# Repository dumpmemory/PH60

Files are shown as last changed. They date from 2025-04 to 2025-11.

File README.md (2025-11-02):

English Version | [中文版](https://github.com/ph-design/PH60/blob/Rev.2/README-zh_CN.md)

---

# PH60 Rev.2
This is a mechanical keyboard with an ISO 60% layout, based on the ISO/IEC 9995 standard.

Watch the detailed introduction on Bilibili!

Bilibili: https://www.bilibili.com/video/BV19Txce7E6C/

We've made a brand new upgrade! Now we've iterated to Rev.2

PH60 Rev.1 Preview all color

## What's new compared to Rev.1
### PCB
We customized this keyboard according to our own ideas while also considering other users' opinions.
- Added the more mainstream ANSI layout, which most people should now feel familiar.

- The PCB has been reduced from 4 layers to 2 layers. Theoretically, the electrical performance has decreased, but it's sufficient for a keyboard, and the cost has been greatly reduced.

- Added support for RGB matrix lighting for both ANSI and ISO layouts.

- Temporarily removed the MOLEX connector and daughter board design as they were not stable enough.
PH60 RGB

- <b>Brand new multi-layout compatible PCB</b>. Compatible with ANSI/ISO/WK/WKL/HHKB, with meticulous routing. This PCB was carefully crafted by our team member [nonameC_](http://www.github.com/nonameCCC).

### Case
PH60 case
PH60 case

Rev2 version introduces innovative designs while maintaining printability, enhancing user experience.

- Magnetic top cover fixation, retaining the snap-fit design

- Innovative "pillow" foot support design, adjustable 7-degree and 0-degree input angles

- Gasket structure design, with specially made thickened positioning plate

- Fully compatible with GH60 standard PCB

- Optimized printing parameters for different printers and materials
  
New version introduction: https://www.bilibili.com/video/BV1fsB8YQELg/

## Design Philosophy

PH60 Rev2 aims to solve the problem of consumer-grade 3D printers being unable to print complete keyboard cases. Through modular design and innovative connection methods, we've achieved high-quality, customizable keyboard cases.

## Usage Guide

1. Download model files from the GitHub repository
2. Choose appropriate slicing parameters based on your printer (Bambu Lab users can get optimized configurations on MakerWorld)
3. Print each component
4. Complete keyboard assembly following the [Assembly Steps](#Assembly-Steps)

---
## Project Structure
```
PH60 Rev.2
├── Case_Model_Rev2                 # Keyboard case 3D model files
├── LICENSE                         # Project license file
├── PCB_Model_Rev2                  # Motherboard 3D model files
├── PCB_Rev2                        # Motherboard PCB design files
├── Plate                           # Positioning plate files
├── Preview                         # Keyboard preview images
├── Production                      # Production files
├── README-zh_CN.md                 # Chinese README
└── README.md                       # English README
```

## Specifications

1. 3D printed case, suitable for any 3D printer with a print size over 250mm x 250mm.
2. Gasket structure for a softer and more flexible typing experience.
3. Designed for plate-mount stabilizers for better typing experience.
4. Equipped with [Raspberry Pi RP2040](https://www.raspberrypi.com/products/rp2040/) microcontroller.
5. Supports open-source [QMK firmware](https://qmk.fm/) and [VIA configuration](https://www.caniusevia.com/) (configured via JSON file).

## Assembly Steps

1. Align the internal markers of the central bottom case and two side cases, ensuring the text direction is consistent. Press the side cases into the central bottom case.

2. Similarly, assemble the two top cover components. After assembly, the top cover should align perfectly. Use a rubber mallet if necessary.

3. Ensure consistent magnet polarity, then press magnets into all designated holes in the bottom case, top cover, and pillow. Use glue if needed.

4. First secure the left snap-fit, then release the cover, allowing the right side to be secured by magnets.

5. Flip the case and secure silicone anti-slip pads to the case and pillow.
   
6. Install the PCB

For more detailed printing and installation steps, please refer to [MakerWorld](https://makerworld.com/zh/models/808113).

## Precautions

If you're hand-soldering the PCB, avoid using Sn42Bi58 low-temperature solder paste. Otherwise, under high-intensity use, it may lead to false soldering between the PCB and hot-swap sockets.

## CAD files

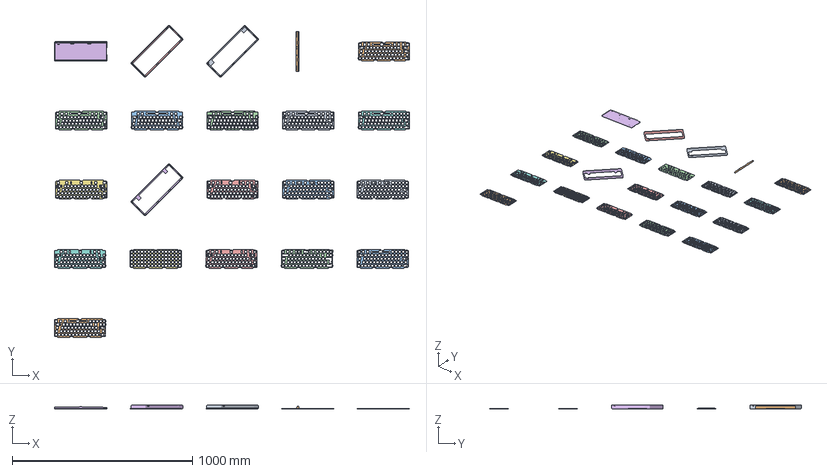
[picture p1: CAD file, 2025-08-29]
Case/PH60i/For Bambu Studio.3mf
1971.1 x 1732.9 x 19.7 mm
outer_case_HHKB
PLANK_(1)
63_Universal_PCBS
WK_PCBS
inner_case
PLANK
HHKB_PCBS
LS64_SSPACE_SB
pillow
LS64_SSPACE
ISO
ANSI_PCBS
outer_case_WKL
WKL_PCBS
LS64
ANSI_SS_SB
ANSI
HHKB
HHKB_Thick
outer_case

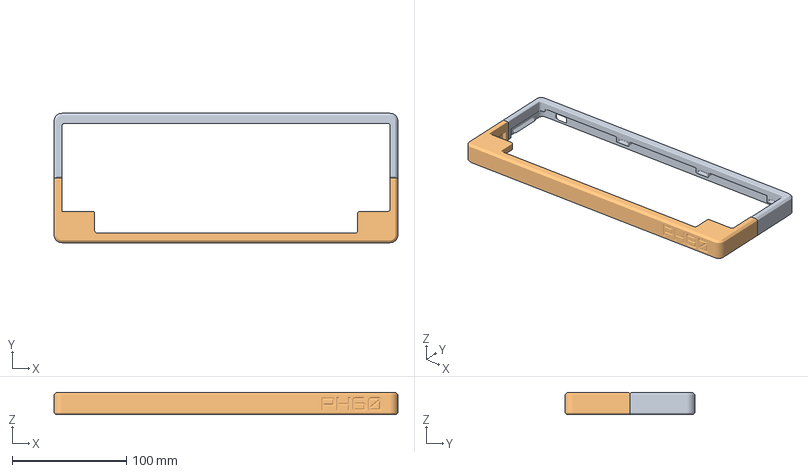
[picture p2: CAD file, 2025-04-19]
Case/PH60Rev2/upper_hhkb.3mf
301.4 x 113.5 x 19.7 mm
outer_case_2
hhkb_outer_case_b

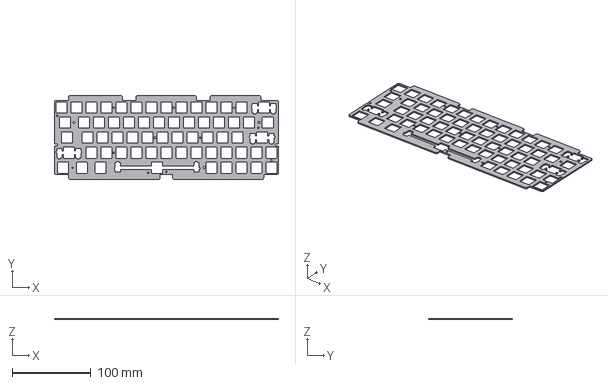
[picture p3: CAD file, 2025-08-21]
Plates_Rev2/3D Model/CAD/K64H3.step
284.2 x 106.2 x 1.50 mm

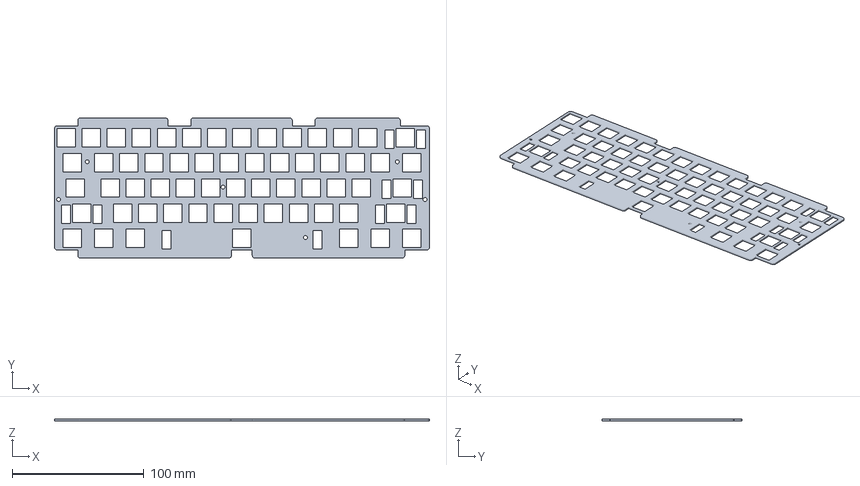
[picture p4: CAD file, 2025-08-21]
Plates_Rev2/3D Model/plate_wk.3mf
284.2 x 106.2 x 1.50 mm

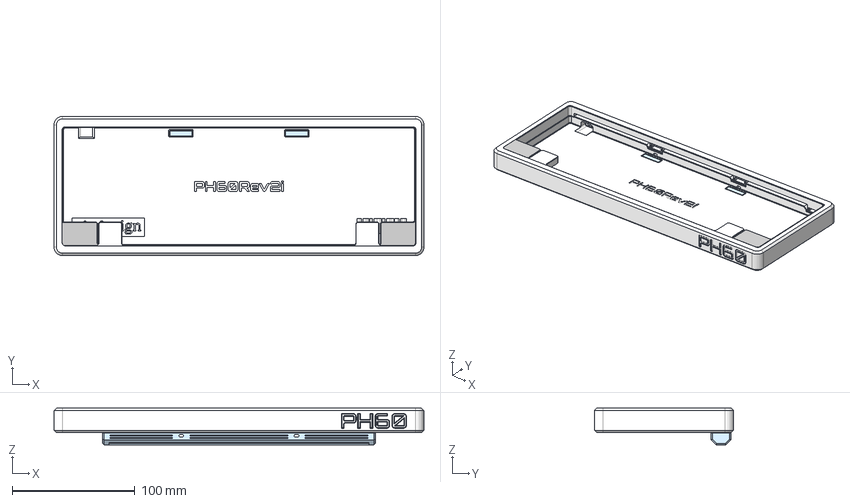
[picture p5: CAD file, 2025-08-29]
Case/PH60i/PH60_Kit_Rev2.2 H2D.step
301.4 x 113.5 x 29.8 mm

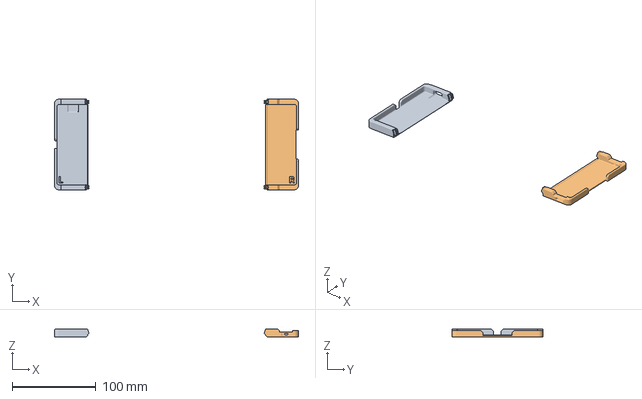
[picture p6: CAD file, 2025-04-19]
Case/PH60Rev2/inner_side.3mf
292.1 x 108.5 x 9.90 mm
inner_case_left
inner_case_right

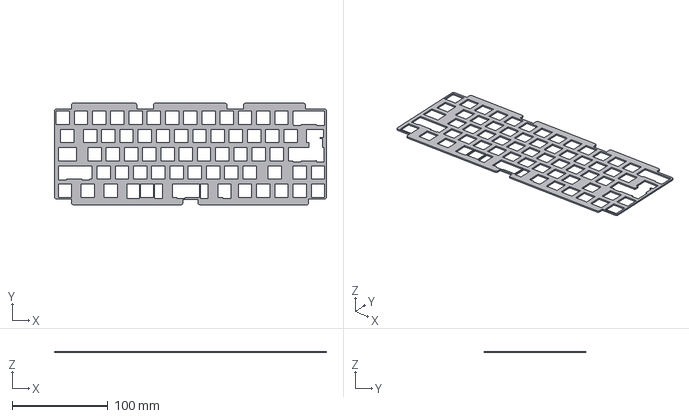
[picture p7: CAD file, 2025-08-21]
Plates_Rev2/3D Model/CAD/63_Universal.step
284.2 x 106.2 x 1.50 mm

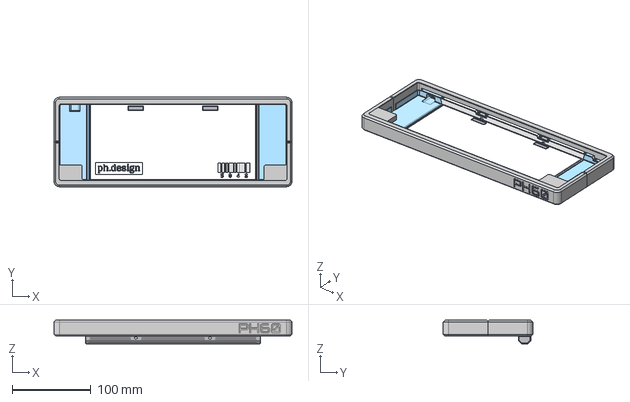
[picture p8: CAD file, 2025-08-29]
Case/PH60i/PH60_Kit_Rev2.2.step
301.4 x 113.5 x 29.8 mm

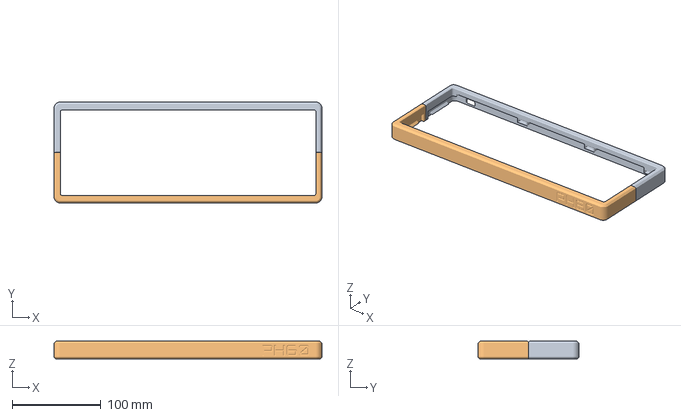
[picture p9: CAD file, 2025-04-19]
Case/PH60Rev2/upper.3mf
301.4 x 113.5 x 19.7 mm
outer_case_2
outer_case_1

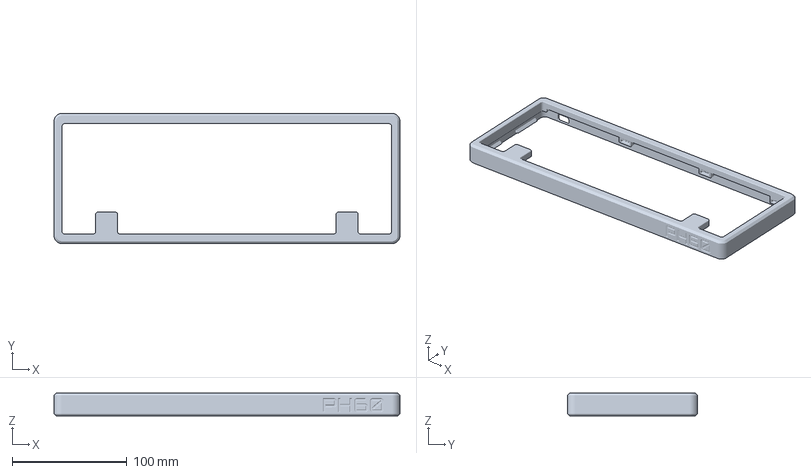
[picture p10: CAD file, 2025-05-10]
Case/PH60i/upper_wkl.3mf
301.4 x 113.5 x 19.7 mm

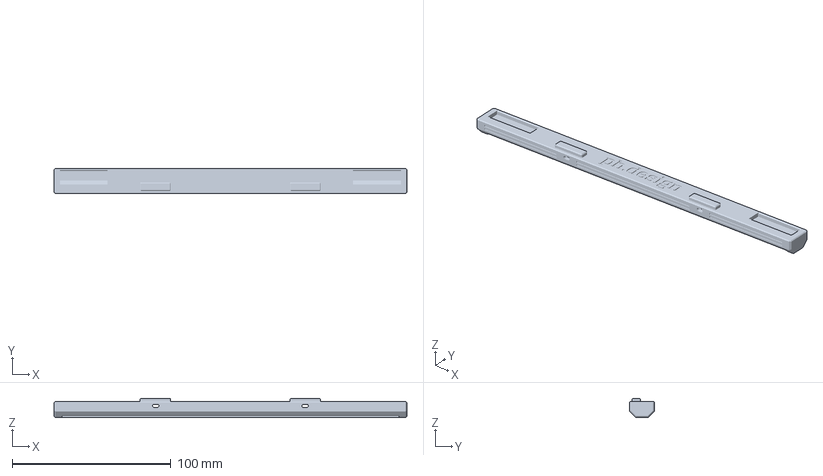
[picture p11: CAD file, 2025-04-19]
Case/PH60Rev2/pillow.3mf
222.1 x 16.0 x 12.1 mm

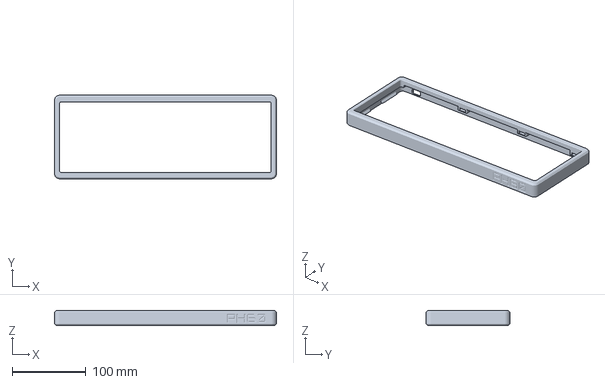
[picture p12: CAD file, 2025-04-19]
Case/PH60i/upper.3mf
301.4 x 113.5 x 19.7 mm

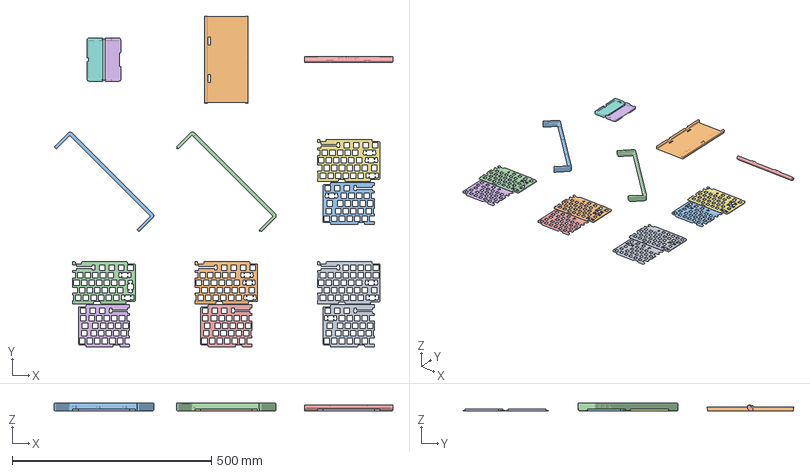
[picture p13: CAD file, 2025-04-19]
Case/PH60Rev2/PH60_suite.3mf
850.6 x 831.3 x 19.7 mm
thick_plate_r_(1) x 3
inner_case_mid
outer_case_2
outer_case_1
pillow
inner_case_right
inner_case_left
thick_plate_l_(1) x 3
thick_plate_r_(2)
thick_plate_l_(2)

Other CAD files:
Plates_Rev2/3D Model/plate_63.3mf
Plates_Rev2/3D Model/CAD/63.step
Plates_Rev2/3D Model/plate_plank.3mf
Plates_Rev2/3D Model/CAD/WK_PCBS.step
Plates_Rev2/3D Model/plate_63_universal_pcbs.3mf
Case/PH60Rev2/For Bambu Studio.3mf
Case/PH60Rev2/inner_mid.3mf
Case/PH60i/inner.3mf
Case/PH60i/pillow.3mf
Case/PH60i/upper_hhkb.3mf
Plates_Rev2/3D Model/CAD/ANSI.step
Plates_Rev2/3D Model/CAD/ANSI_PCBS.step
Plates_Rev2/3D Model/CAD/ANSI_SS_SB.step
Plates_Rev2/3D Model/CAD/HHKB.step
Plates_Rev2/3D Model/CAD/HHKB_PCBS.step
Plates_Rev2/3D Model/CAD/HHKB_thick.step
Plates_Rev2/3D Model/CAD/ISO.step
Plates_Rev2/3D Model/CAD/LS64.step
Plates_Rev2/3D Model/CAD/LS64_SSPACE.step
Plates_Rev2/3D Model/CAD/LS64_SSPACE_SB.step
Plates_Rev2/3D Model/CAD/PLANK.step
Plates_Rev2/3D Model/CAD/WKL_PCBS.step
Plates_Rev2/3D Model/k64h3.3mf
Plates_Rev2/3D Model/plate_K64H3MZ.3mf
Plates_Rev2/3D Model/plate_ansi.3mf
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

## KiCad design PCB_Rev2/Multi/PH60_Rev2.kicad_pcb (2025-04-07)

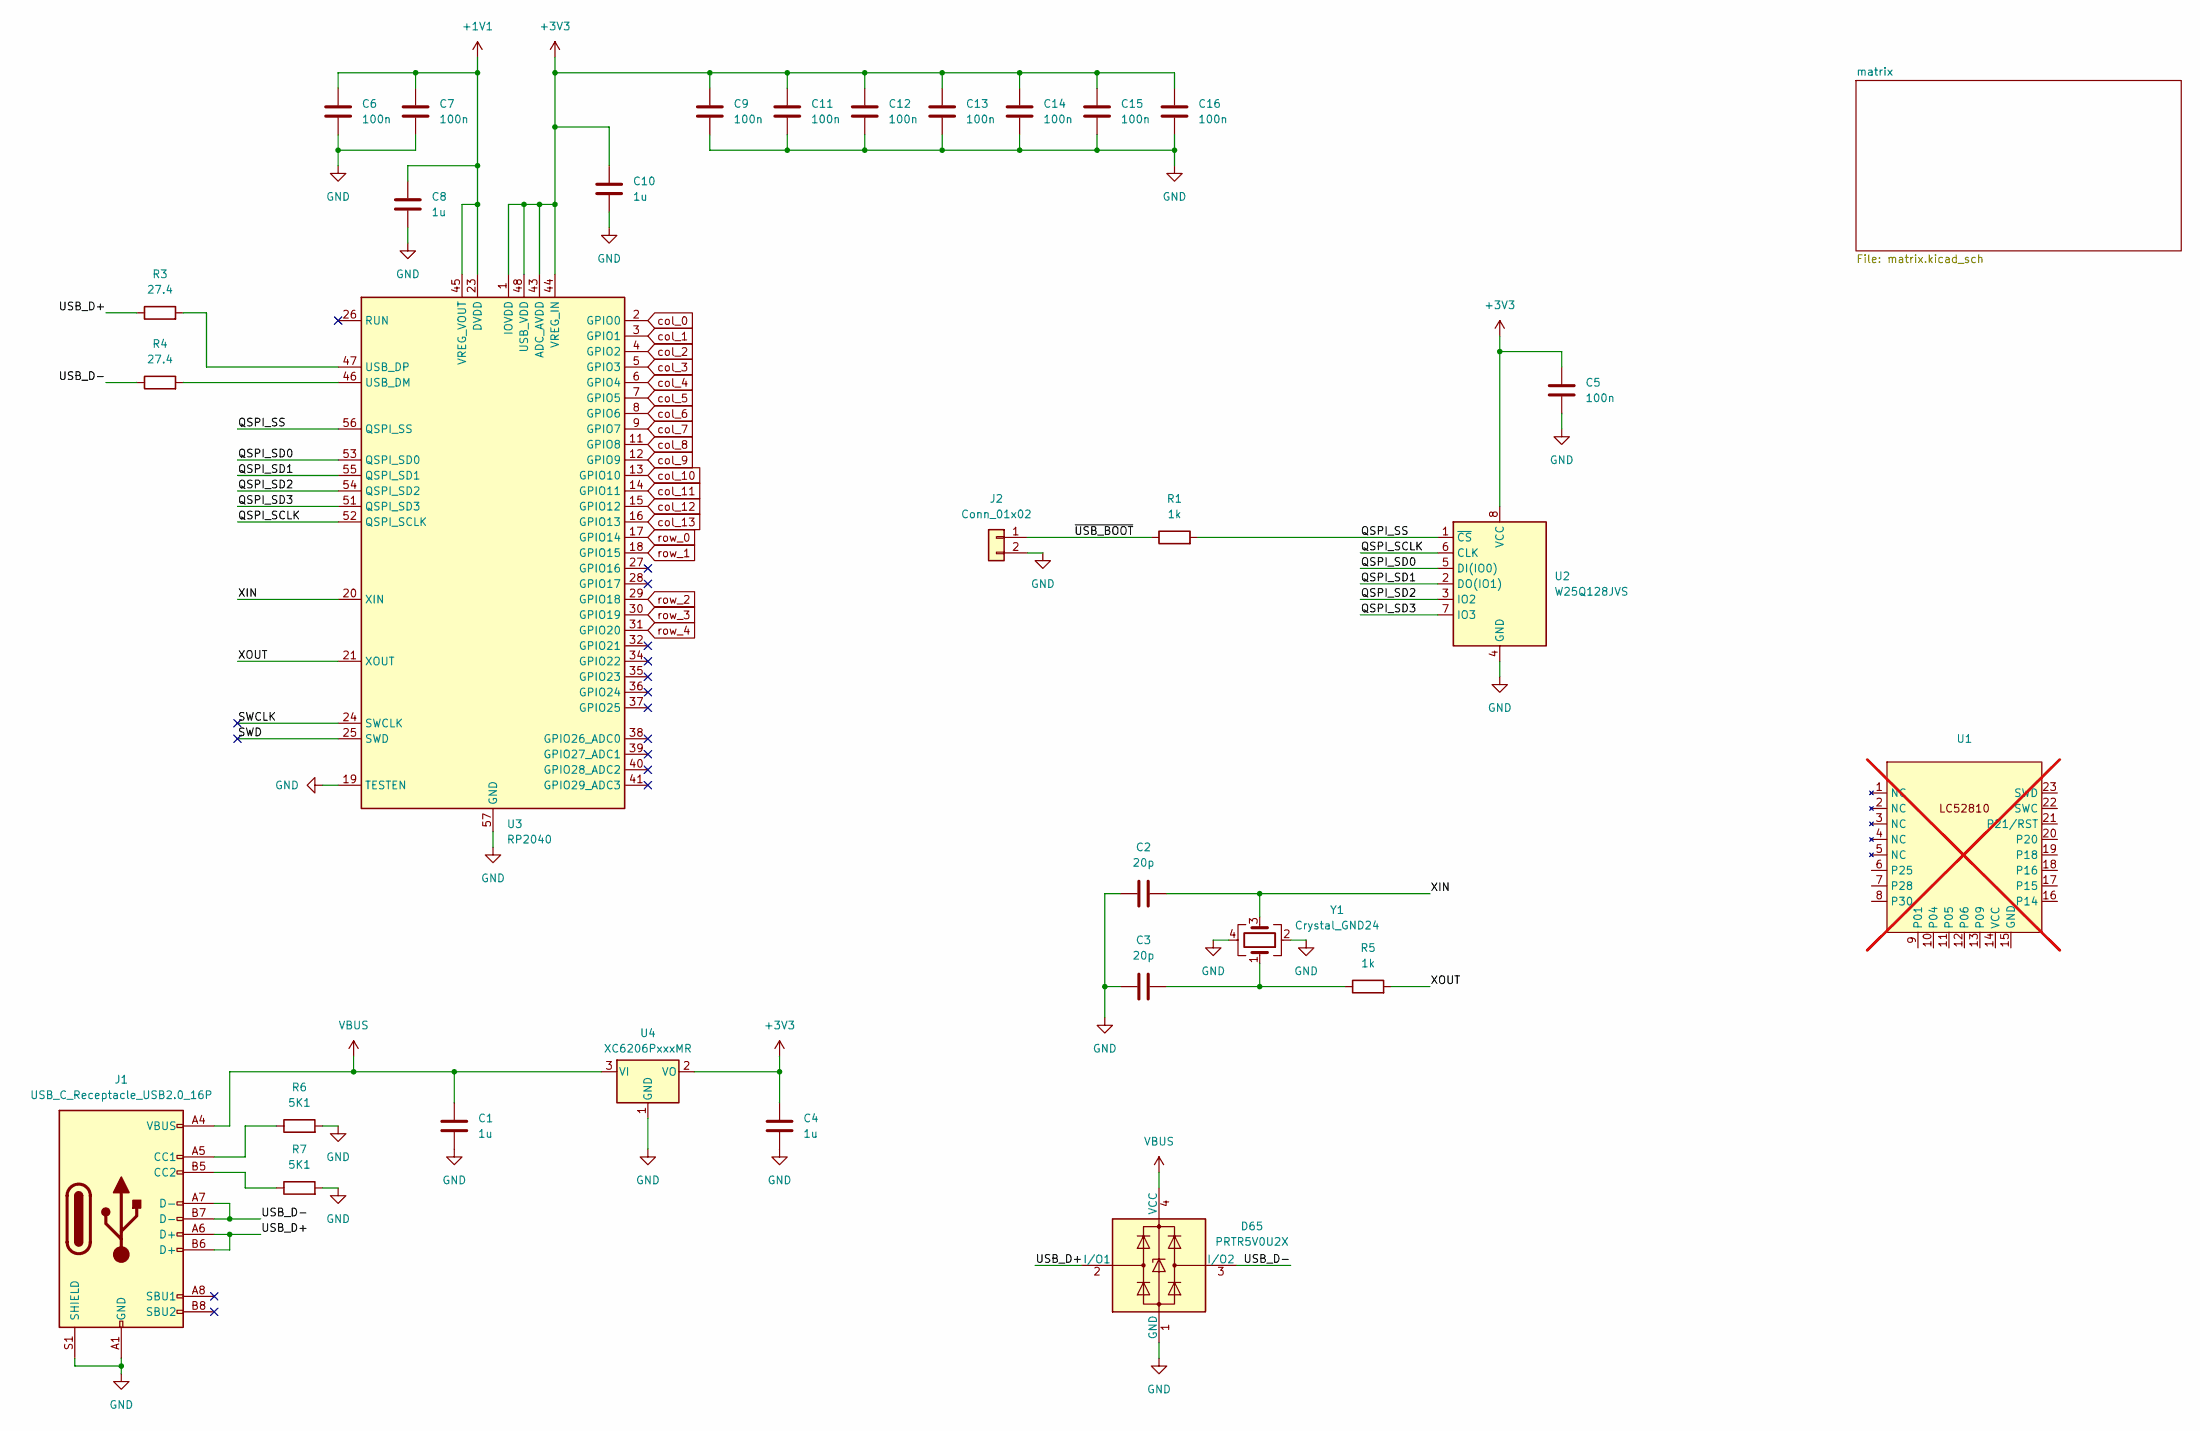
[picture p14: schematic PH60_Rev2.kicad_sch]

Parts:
C1, C4, C8, C10: 1u; C_0402_1005Metric
C2, C3: 20p; C_0402_1005Metric
C5, C6, C7, C9, C11, C12, C13, C14, C15, C16: 100n; C_0402_1005Metric
D65: PRTR5V0U2X; SOT-143
J1: USB_C_Receptacle_USB2.0_16P; USB_C_Receptacle_GCT_USB4105-xx-A_16P_TopMnt_Horizontal
J2: Conn_01x02; PinHeader_1x02_P1.27mm_Vertical
R1, R5: 1k; R_0402_1005Metric
R3, R4: 27.4; R_0402_1005Metric
R6, R7: 5K1; R_0402_1005Metric
U1: nRF52810_Module; not fitted
U2: W25Q128JVS; Winbond_USON-8-1EP_3x2mm_P0.5mm_EP0.2x1.6mm
U3: RP2040; QFN-56-1EP_7x7mm_P0.4mm_EP3.2x3.2mm
U4: XC6206PxxxMR; SOT-23-3
Y1: Crystal_GND24; Crystal_SMD_3225-4Pin_3.2x2.5mm

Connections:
+1V1: C6.1, C7.1, C8.1, U3.23 (DVDD), U3.45 (VREG_VOUT), U3.50 (DVDD)
+3V3: C4.1, C5.1, C9.1, C10.1, C11.1, C12.1, C13.1, C14.1, C15.1, C16.1, U2.8 (VCC), U3.1 (IOVDD), U3.10 (IOVDD), U3.22 (IOVDD), U3.33 (IOVDD), U3.42 (IOVDD), U3.43 (ADC_AVDD), U3.44 (VREG_IN), U3.48 (USB_VDD), U3.49 (IOVDD), U4.2 (VO)
/QSPI_SCLK: U2.6 (CLK), U3.52 (QSPI_SCLK)
/QSPI_SD0: U2.5 (DI(IO0)), U3.53 (QSPI_SD0)
/QSPI_SD1: U2.2 (DO(IO1)), U3.55 (QSPI_SD1)
/QSPI_SD2: U2.3 (IO2), U3.54 (QSPI_SD2)
/QSPI_SD3: U2.7 (IO3), U3.51 (QSPI_SD3)
/QSPI_SS: R1.2, U2.1 (~CS), U3.56 (QSPI_SS)
/SWCLK: U3.24 (SWCLK)
/SWD: U3.25 (SWD)
/USB_D+: D65.2 (I/O1), J1.A6 (D+), J1.B6 (D+), R3.1
/USB_D-: D65.3 (I/O2), J1.A7 (D-), J1.B7 (D-), R4.1
/XIN: C2.1, U3.20 (XIN), Y1.3
/XOUT: R5.2, U3.21 (XOUT)
/~USB_BOOT: J2.1, R1.1
GND: C1.2, C2.2, C3.2, C4.2, C5.2, C6.2, C7.2, C8.2, C9.2, C10.2, C11.2, C12.2, C13.2, C14.2, C15.2, C16.2, D65.1 (GND), J1.A1 (GND), J1.A12 (GND), J1.B1 (GND), J1.B12 (GND), J1.S1 (SHIELD), J2.2, R6.2, R7.2, U2.4 (GND), U3.19 (TESTEN), U3.57 (GND), U4.1 (GND), Y1.2, Y1.4
unnamed: C3.1, R5.1, Y1.1
unnamed: J1.A5 (CC1), R6.1
unnamed: J1.B5 (CC2), R7.1
unnamed: R4.2, U3.46 (USB_DM)
unnamed: R3.2, U3.47 (USB_DP)
VBUS: C1.1, D65.4 (VCC), J1.A4 (VBUS), J1.A9 (VBUS), J1.B4 (VBUS), J1.B9 (VBUS), U4.3 (VI)
col_0: U3.2 (GPIO0); also elsewhere on the board
col_1: U3.3 (GPIO1); also elsewhere on the board
col_2: U3.4 (GPIO2); also elsewhere on the board
col_3: U3.5 (GPIO3); also elsewhere on the board
col_4: U3.6 (GPIO4); also elsewhere on the board
col_5: U3.7 (GPIO5); also elsewhere on the board
col_6: U3.8 (GPIO6); also elsewhere on the board
col_7: U3.9 (GPIO7); also elsewhere on the board
col_8: U3.11 (GPIO8); also elsewhere on the board
col_9: U3.12 (GPIO9); also elsewhere on the board
col_10: U3.13 (GPIO10); also elsewhere on the board
col_11: U3.14 (GPIO11); also elsewhere on the board
col_12: U3.15 (GPIO12); also elsewhere on the board
col_13: U3.16 (GPIO13); also elsewhere on the board
row_0: U3.17 (GPIO14); also elsewhere on the board
row_1: U3.18 (GPIO15); also elsewhere on the board
row_2: U3.29 (GPIO18); also elsewhere on the board
row_3: U3.30 (GPIO19); also elsewhere on the board
row_4: U3.31 (GPIO20); also elsewhere on the board

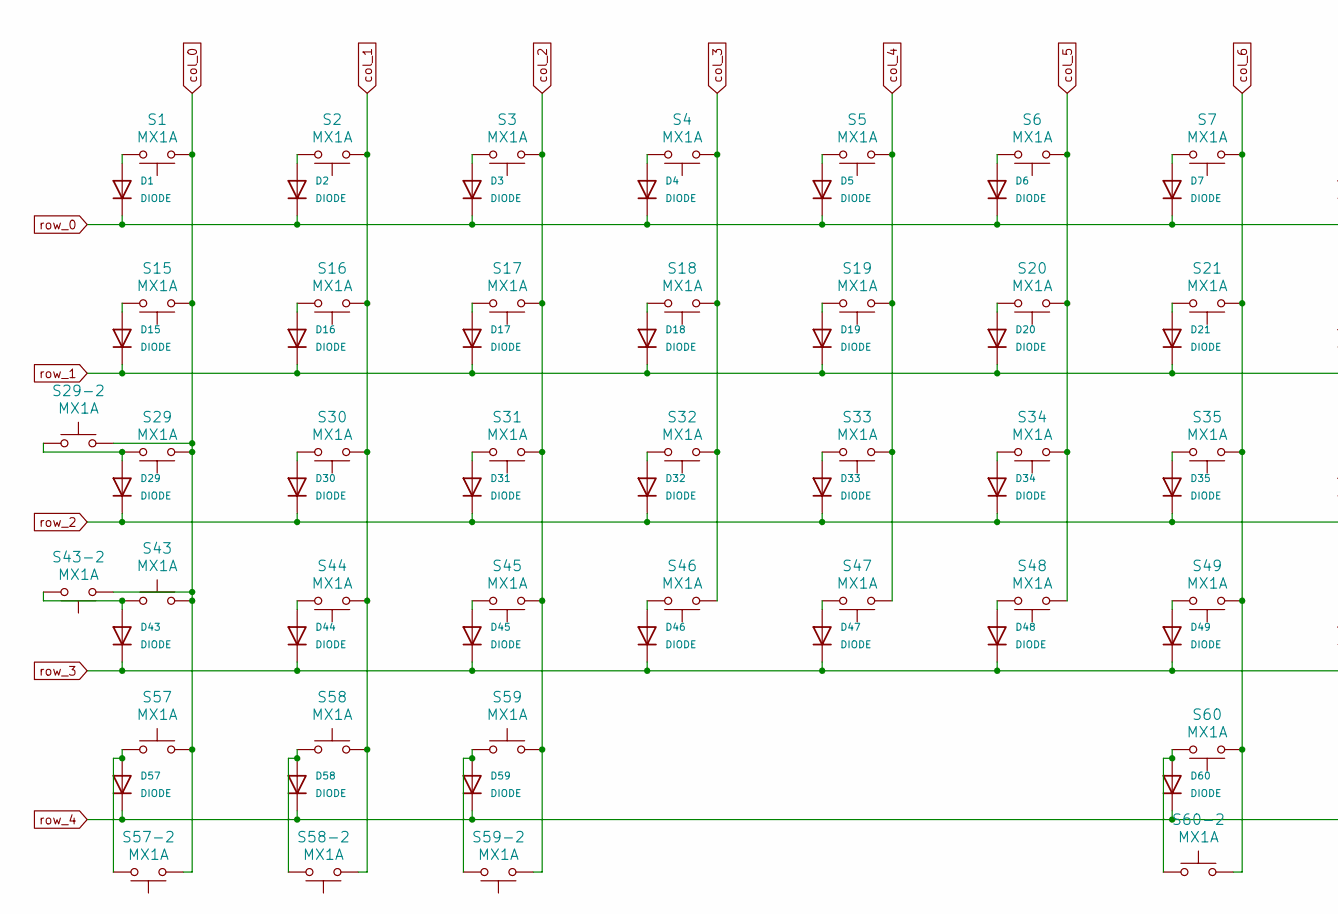
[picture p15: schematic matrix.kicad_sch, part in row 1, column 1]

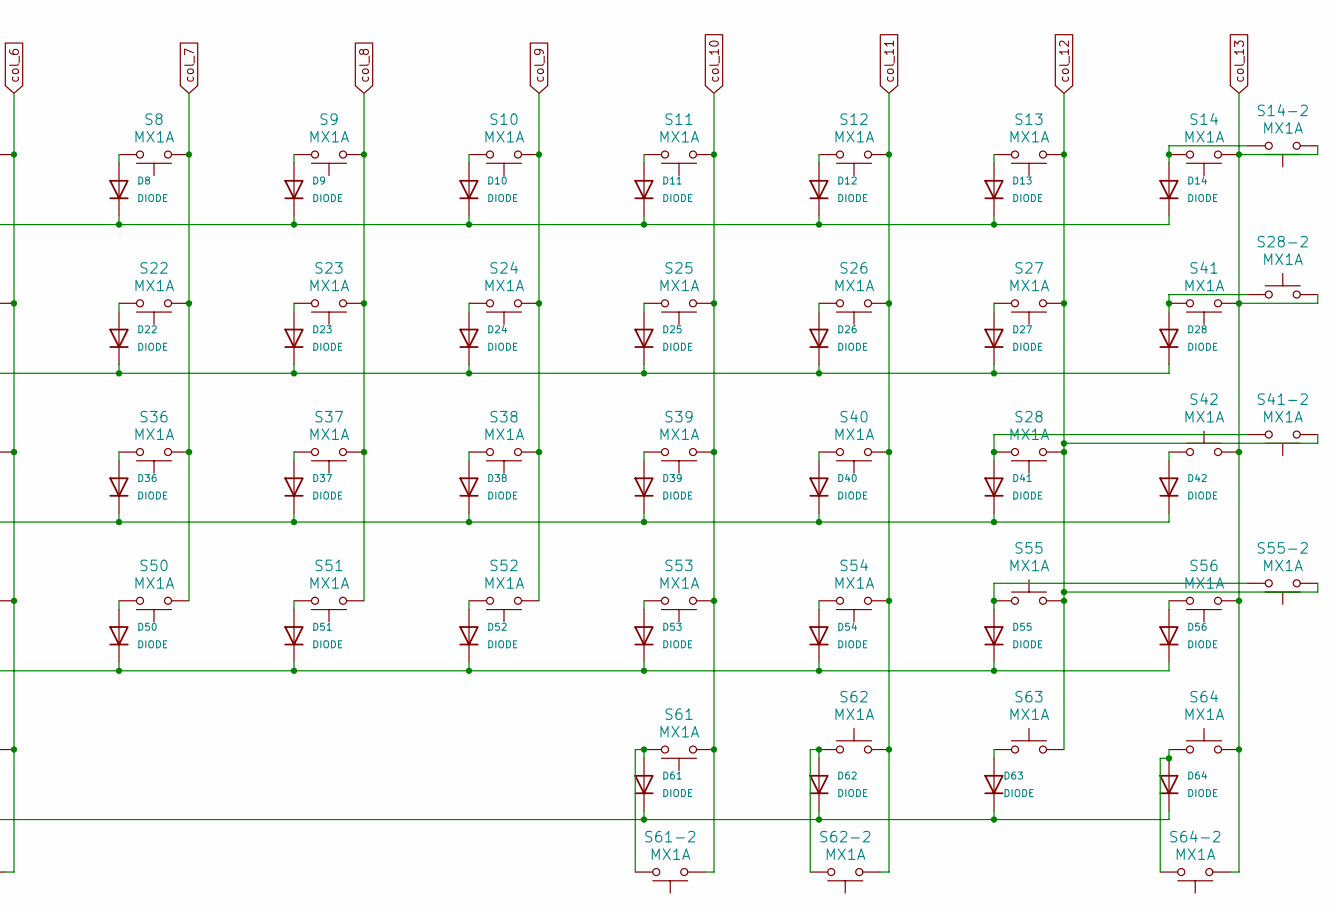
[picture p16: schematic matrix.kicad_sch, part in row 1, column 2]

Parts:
D1, D2, D3, D4, D5, D6, D7, D8, D9, D10, D11, D12, D13, D14, D15, D16, D17, D18, D19, D20, D21, D22, D23, D24, D25, D26, D27, D28, D29, D30, D31, D32, D33, D34, D35, D36, D37, D38, D39, D40, D41, D42, D43, D44, D45, D46, D47, D48, D49, D50, D51, D52, D53, D54, D55, D56, D57, D58, D59, D60, D61, D62, D63, D64: DIODE; D_SOD-123
S1, S2, S3, S4, S5, S6, S7, S8, S9, S10, S11, S12, S13, S14-2, S16, S17, S18, S19, S20, S21, S22, S23, S24, S25, S26, S27, S30, S31, S32, S33, S34, S35, S36, S37, S38, S39, S40, S41, S42, S44, S45, S46, S47, S48, S49, S50, S51, S52, S53, S54, S56, S58-2, S62-2: MX1A; SW_Hotswap_Kailh_MX_Plated_1.00u
S14: MX1A; SW_Hotswap_Kailh_MX_Plated_2.00u
S15, S57-2, S59-2, S61-2, S64-2: MX1A; SW_Hotswap_Kailh_MX_Plated_1.50u
S28: MX1A; SW_Hotswap_Kailh_MX_Plated_ISOEnter_90deg
S28-2: MX1A; SW_Hotswap_Kailh_MX_Plated_1.50u_90deg
S29, S55: MX1A; SW_Hotswap_Kailh_MX_Plated_1.75u
S29-2, S43, S57, S58, S59, S61, S62, S63, S64: MX1A; SW_Hotswap_Kailh_MX_Plated_1.25u
S41-2: MX1A; SW_Hotswap_Kailh_MX_Plated_2.25u_90deg
S43-2: MX1A; SW_Hotswap_Kailh_MX_Plated_2.25u
S55-2: MX1A; SW_Hotswap_Kailh_MX_Plated_2.75u
S60: MX1A; SW_Hotswap_Kailh_MX_Plated_6.25u
S60-2: MX1A; SW_Hotswap_Kailh_MX_Plated_7.00u

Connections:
unnamed: D1.2 (A), S1.1
unnamed: D2.2 (A), S2.1
unnamed: D3.2 (A), S3.1
unnamed: D4.2 (A), S4.1
unnamed: D5.2 (A), S5.1
unnamed: D6.2 (A), S6.1
unnamed: D7.2 (A), S7.1
unnamed: D8.2 (A), S8.1
unnamed: D9.2 (A), S9.1
unnamed: D10.2 (A), S10.1
unnamed: D11.2 (A), S11.1
unnamed: D12.2 (A), S12.1
unnamed: D13.2 (A), S13.1
unnamed: D14.2 (A), S14.1, S14-2.1
unnamed: D15.2 (A), S15.1
unnamed: D16.2 (A), S16.1
unnamed: D17.2 (A), S17.1
unnamed: D18.2 (A), S18.1
unnamed: D19.2 (A), S19.1
unnamed: D20.2 (A), S20.1
unnamed: D21.2 (A), S21.1
unnamed: D22.2 (A), S22.1
unnamed: D23.2 (A), S23.1
unnamed: D24.2 (A), S24.1
unnamed: D25.2 (A), S25.1
unnamed: D26.2 (A), S26.1
unnamed: D27.2 (A), S27.1
unnamed: D28.2 (A), S28-2.2, S41.1
unnamed: D29.2 (A), S29.1, S29-2.2
unnamed: D30.2 (A), S30.1
unnamed: D31.2 (A), S31.1
unnamed: D32.2 (A), S32.1
unnamed: D33.2 (A), S33.1
unnamed: D34.2 (A), S34.1
unnamed: D35.2 (A), S35.1
unnamed: D36.2 (A), S36.1
unnamed: D37.2 (A), S37.1
unnamed: D38.2 (A), S38.1
unnamed: D39.2 (A), S39.1
unnamed: D40.2 (A), S40.1
unnamed: D41.2 (A), S28.1, S41-2.1
unnamed: D42.2 (A), S42.2
unnamed: D43.2 (A), S43.2, S43-2.1
unnamed: D44.2 (A), S44.1
unnamed: D45.2 (A), S45.1
unnamed: D46.2 (A), S46.1
unnamed: D47.2 (A), S47.1
unnamed: D48.2 (A), S48.1
unnamed: D49.2 (A), S49.1
unnamed: D50.2 (A), S50.1
unnamed: D51.2 (A), S51.1
unnamed: D52.2 (A), S52.1
unnamed: D53.2 (A), S53.1
unnamed: D54.2 (A), S54.1
unnamed: D55.2 (A), S55.2, S55-2.1
unnamed: D56.2 (A), S56.1
unnamed: D57.2 (A), S57.2, S57-2.1
unnamed: D58.2 (A), S58.2, S58-2.1
unnamed: D59.2 (A), S59.2, S59-2.1
unnamed: D60.2 (A), S60.1, S60-2.2
unnamed: D61.2 (A), S61.1, S61-2.1
unnamed: D62.2 (A), S62.2, S62-2.1
unnamed: D63.2 (A), S63.2
unnamed: D64.2 (A), S64.2, S64-2.1
col_0: S1.2, S15.2, S29.2, S29-2.1, S43.1, S43-2.2, S57.1, S57-2.2; also elsewhere on the board
col_1: S2.2, S16.2, S30.2, S44.2, S58.1, S58-2.2; also elsewhere on the board
col_2: S3.2, S17.2, S31.2, S45.2, S59.1, S59-2.2; also elsewhere on the board
col_3: S4.2, S18.2, S32.2, S46.2; also elsewhere on the board
col_4: S5.2, S19.2, S33.2, S47.2; also elsewhere on the board
col_5: S6.2, S20.2, S34.2, S48.2; also elsewhere on the board
col_6: S7.2, S21.2, S35.2, S49.2, S60.2, S60-2.1; also elsewhere on the board
col_7: S8.2, S22.2, S36.2, S50.2; also elsewhere on the board
col_8: S9.2, S23.2, S37.2, S51.2; also elsewhere on the board
col_9: S10.2, S24.2, S38.2, S52.2; also elsewhere on the board
col_10: S11.2, S25.2, S39.2, S53.2, S61.2, S61-2.2; also elsewhere on the board
col_11: S12.2, S26.2, S40.2, S54.2, S62.1, S62-2.2; also elsewhere on the board
col_12: S13.2, S27.2, S28.2, S41-2.2, S55.1, S55-2.2, S63.1; also elsewhere on the board
col_13: S14.2, S14-2.2, S28-2.1, S41.2, S42.1, S56.2, S64.1, S64-2.2; also elsewhere on the board
row_0: D1.1 (K), D2.1 (K), D3.1 (K), D4.1 (K), D5.1 (K), D6.1 (K), D7.1 (K), D8.1 (K), D9.1 (K), D10.1 (K), D11.1 (K), D12.1 (K), D13.1 (K), D14.1 (K); also elsewhere on the board
row_1: D15.1 (K), D16.1 (K), D17.1 (K), D18.1 (K), D19.1 (K), D20.1 (K), D21.1 (K), D22.1 (K), D23.1 (K), D24.1 (K), D25.1 (K), D26.1 (K), D27.1 (K), D28.1 (K); also elsewhere on the board
row_2: D29.1 (K), D30.1 (K), D31.1 (K), D32.1 (K), D33.1 (K), D34.1 (K), D35.1 (K), D36.1 (K), D37.1 (K), D38.1 (K), D39.1 (K), D40.1 (K), D41.1 (K), D42.1 (K); also elsewhere on the board
row_3: D43.1 (K), D44.1 (K), D45.1 (K), D46.1 (K), D47.1 (K), D48.1 (K), D49.1 (K), D50.1 (K), D51.1 (K), D52.1 (K), D53.1 (K), D54.1 (K), D55.1 (K), D56.1 (K); also elsewhere on the board
row_4: D57.1 (K), D58.1 (K), D59.1 (K), D60.1 (K), D61.1 (K), D62.1 (K), D63.1 (K), D64.1 (K); also elsewhere on the board

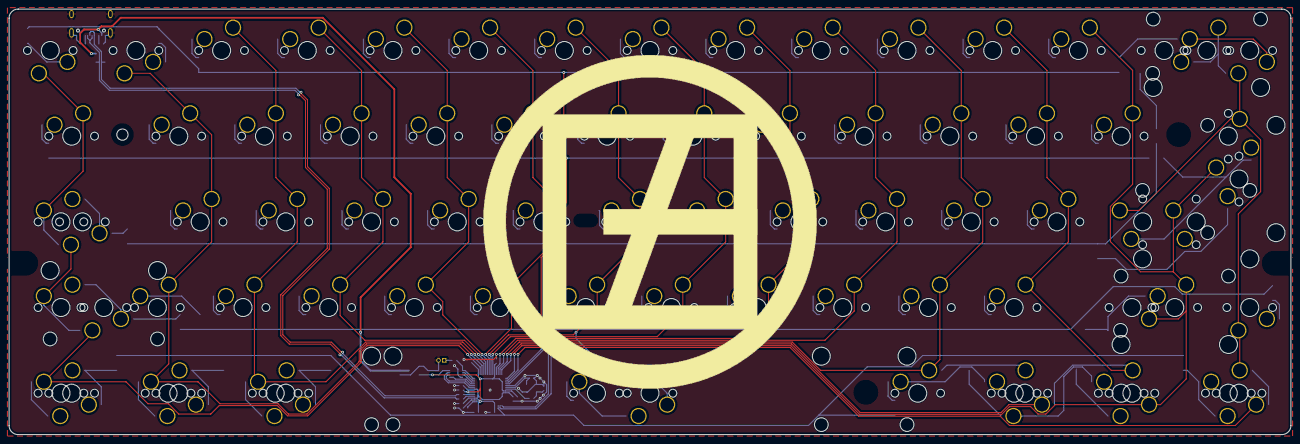
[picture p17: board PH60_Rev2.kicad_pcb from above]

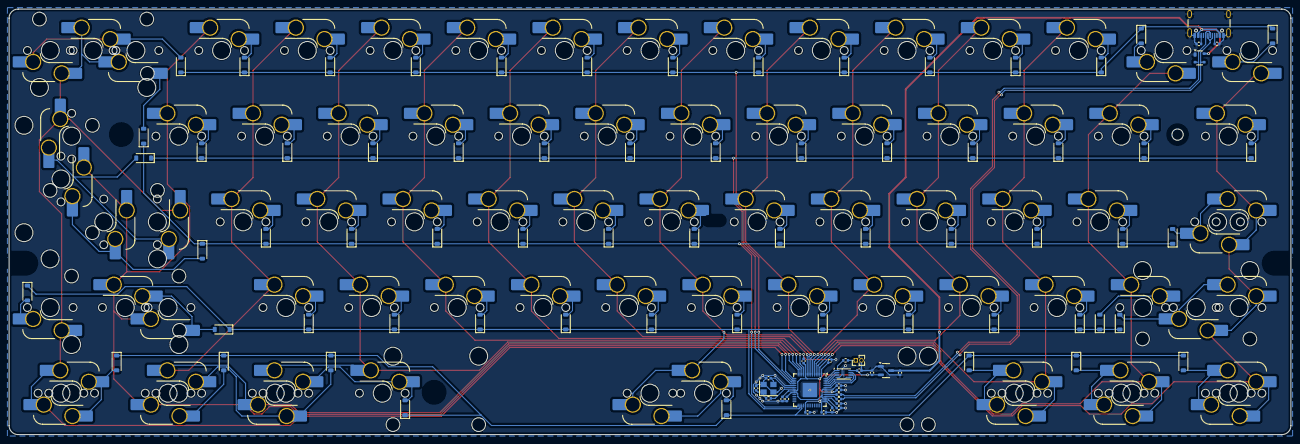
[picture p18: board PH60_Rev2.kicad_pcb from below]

Board: 2 copper layers, 285.0 x 94.6 mm, 176 parts (93 on the bottom side), 103 nets.

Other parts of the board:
HOLE: VAL**; PKRH
HOLE#2, HOLE#6: VAL**; PKRH
HOLE#3, HOLE#5: VAL**; PKRHSL
HOLE#4: VAL**; PKRHC

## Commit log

2025-04-07 Multi PCB Update
    [PH60_Rev2.kicad_pcb, PH60_Rev2.kicad_sch, matrix.kicad_sch]
2025-04-19 Add more plates
    Designed for PH60i, but also capable for Rev2.
    [ANSI.dxf, ANSI_SS_SB.dxf, HHKB.dxf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]
2025-04-19 Rearrange all the 3d cad files.
    + Add intergraded PH60 models.
    + Add fine tuned mounting plates.
    + Add CAD files of plates models.
    + Add Sliced files for Bambu Studio.
    [ANSI.step, ANSI_SS_SB.step, For Bambu Studio.3mf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]
2025-04-27 Update left-shift-64 plate and CAD files
    + Add LS64 CAD files
    + Update LS64 plate.3mf
    + Add LS64 draft file
    [LS64.dxf, LS64.step, plate_ls64.3mf]
2025-05-10 Add WKL, ANSI with PCB stabilizer layout
    [ANSI.step, ANSI_PCBS.step, WKL_PCBS.step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]
2025-06-04 Add more plates
    [ANSI_PCBS.dxf, LS64_SSPACE.dxf, LS64_SSPACE.step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]
2025-06-12 Add HHKB PCB_stabs plate
    [HHKB_PCBS.dxf, HHKB_PCBS.step, plate_hhkb_pcbs.3mf]
2025-08-17 Add plates via submodule
    [ANSI.dxf, ANSI.step, ANSI_PCBS.dxf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]
2025-08-21 Add K64H3 plate
    [63.dxf, 63.step, 63_Universal.dxf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]
2025-08-29 Add STEP file for rev2.2 case.
    + Add STEP files for rev2.2 case.
    + Add new sliced file.
    [For Bambu Studio.3mf, PH60_Kit_Rev2.2 H2D.step, PH60_Kit_Rev2.2.step]
2025-08-29 Revert "Delete Plate directory"
    This reverts commit d811f289309ab6a0be88b70d2a19a5fe3f2885f7.
    [63.dxf, 63.step, 63_Universal.dxf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]
2026-04-19 Project structure update
    [63.dxf, 63.step, 63_Universal.dxf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]
